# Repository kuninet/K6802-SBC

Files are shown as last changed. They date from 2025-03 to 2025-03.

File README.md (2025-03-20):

# MC6802 MPUを使ったシングルボードコンピューター

## REV1はシリアルクロック回路にバグがあります!!
## REV2で修正

## 概要
* MC6802 MPUを使ったシングルボードコンピューターです。
  * MC6850 ACIA経由でシリアルターミナル(TeraTermなど)とつながります。(SBC6800と互換)
  * 64kBのメモリー領域にRAMをわりあてるため128kB SRAMを使用しています。(半分の64kBは無駄にしています)
    * 半田ジャンパによりメモリー領域を調整可能です。(外部ボードのRAM用にディセーブル or ROM領域へ割り当て)
  * ROMは32kBタイプですが、ジャンパで2つの領域に分けて使用できます。
* SBC6800のソフトを使えることを目指しました。

## 回路図
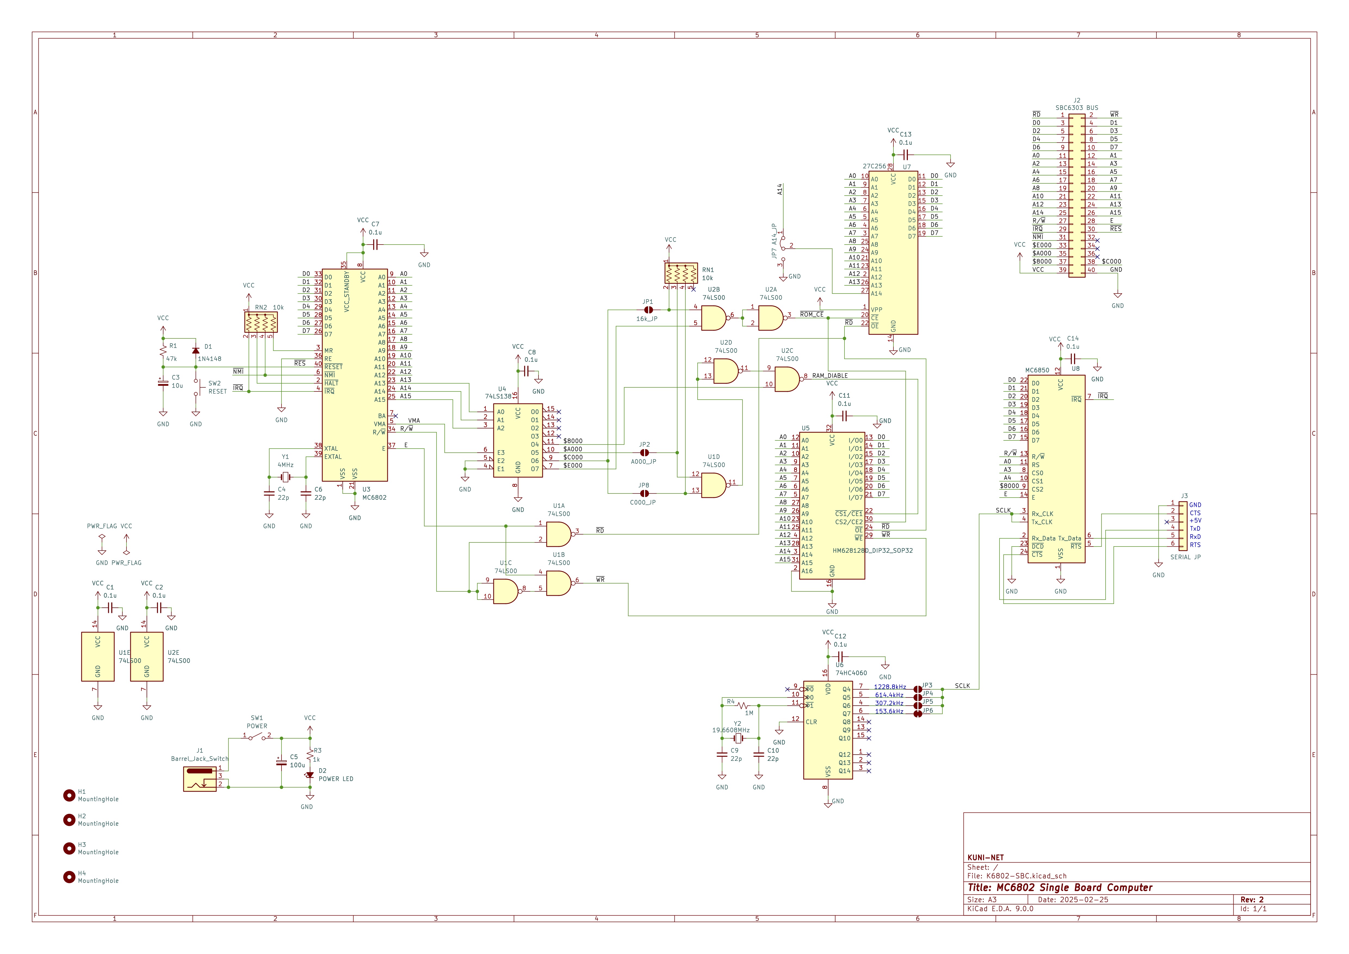
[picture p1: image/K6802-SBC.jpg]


## 部品表
[部品表](KiCad/K6802-SBC.csv)

## ブラウザで回路図などを確認
* Kicadcanvas
  * https://kicanvas.org/?github=https%3A%2F%2Fgithub.com%2Fkuninet%2FK6802-SBC%2Ftree%2Fmain%2FKiCad

## 参考
* 以下の回路を参考にさせていただきました。ありがとうございます。
  * [SBC6800 ルーズキット (電脳伝説さん)](https://vintagechips.wordpress.com/2017/12/05/sbc6800%E3%83%AB%E3%83%BC%E3%82%BA%E3%82%AD%E3%83%83%E3%83%88/)
  * [SBC-IO Rev02 (Tomi9さん)](https://sbc738827564.wordpress.com/2018/08/11/sbc-io-rev02/)
  * [SBC8080 SUBルーズキット (電脳伝説さん)](https://vintagechips.wordpress.com/2018/06/23/sbc8080-sub%E3%83%AB%E3%83%BC%E3%82%BA%E3%82%AD%E3%83%83%E3%83%88/)
  * [SBC6802 (ryu10さん)](https://github.com/ryu10/sbc6802)

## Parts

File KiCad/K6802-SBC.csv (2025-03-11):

Reference | Value | Datasheet | Footprint | Qty | DNP
C1,C2,C7,C8,C11,C12,C13,C14 | 0.1u | ~ | Capacitor_THT:C_Disc_D3.0mm_W2.0mm_P2.50mm | 8
C3 | 10u | ~ | Capacitor_THT:CP_Radial_D5.0mm_P2.50mm | 1
C4,C6,C9,C10 | 22p | ~ | Capacitor_THT:C_Disc_D3.0mm_W2.0mm_P2.50mm | 4
C5 | 100u | ~ | Capacitor_THT:CP_Radial_D5.0mm_P2.50mm | 1
D1 | 1N4148 | ~ | Diode_THT:D_A-405_P10.16mm_Horizontal | 1
D2 | POWER LED | ~ | LED_THT:LED_D3.0mm | 1
H1,H2,H3,H4 | MountingHole | ~ | MountingHole:MountingHole_3.2mm_M3 | 4
J1 | Barrel_Jack_Switch | ~ | Connector_BarrelJack:BarrelJack_Horizontal | 1
J2 | SBC6303 BUS | ~ | Connector_PinHeader_2.54mm:PinHeader_2x20_P2.54mm_Horizontal | 1
J3 | SERIAL JP | ~ | Connector_PinHeader_2.54mm:PinHeader_1x06_P2.54mm_Horizontal | 1
R1 | 47k | ~ | Resistor_THT:R_Axial_DIN0207_L6.3mm_D2.5mm_P10.16mm_Horizontal | 1
R3 | 1k | ~ | Resistor_THT:R_Axial_DIN0207_L6.3mm_D2.5mm_P10.16mm_Horizontal | 1
R4 | 1M | ~ | Resistor_THT:R_Axial_DIN0207_L6.3mm_D2.5mm_P10.16mm_Horizontal | 1
RN1,RN2 | 10k | http://www.vishay.com/docs/31509/csc.pdf | Resistor_THT:R_Array_SIP5 | 2
SW1 | POWER | ~ | Connector_PinHeader_2.54mm:PinHeader_1x03_P2.54mm_Vertical | 1
SW2 | RESET | ~ | Button_Switch_THT:SW_PUSH_6mm | 1
U1,U2 | 74LS00 | http://www.ti.com/lit/gpn/sn74ls00 | Package_DIP:DIP-14_W7.62mm_Socket | 2
U3 | MC6802 | https://www.jameco.com/Jameco/Products/ProdDS/43502.pdf | Package_DIP:DIP-40_W15.24mm_Socket | 1
U4 | 74LS138 | http://www.ti.com/lit/gpn/sn74LS138 | Package_DIP:DIP-16_W7.62mm_Socket | 1
U5 | HM628128D_DIP32_SOP32 | http://www.futurlec.com/Datasheet/Memory/628128.pdf | Package_DIP:DIP-32_W15.24mm_Socket | 1
U6 | 74HC4060 | https://www.st.com/resource/en/datasheet/m74hc4060.pdf | Package_DIP:DIP-16_W7.62mm_Socket | 1
U7 | 27C256 | http://ww1.microchip.com/downloads/en/DeviceDoc/doc0014.pdf | Package_DIP:DIP-28_W15.24mm_Socket | 1
U8 | MC6850 | http://pdf.datasheetcatalog.com/datasheet/motorola/MC6850.pdf | Package_DIP:DIP-24_W15.24mm_Socket | 1
Y1 | 4MHz | ~ | Crystal:Crystal_HC49-U_Vertical | 1
Y2 | 19.6608MHz | ~ | Crystal:Crystal_HC49-U_Vertical | 1

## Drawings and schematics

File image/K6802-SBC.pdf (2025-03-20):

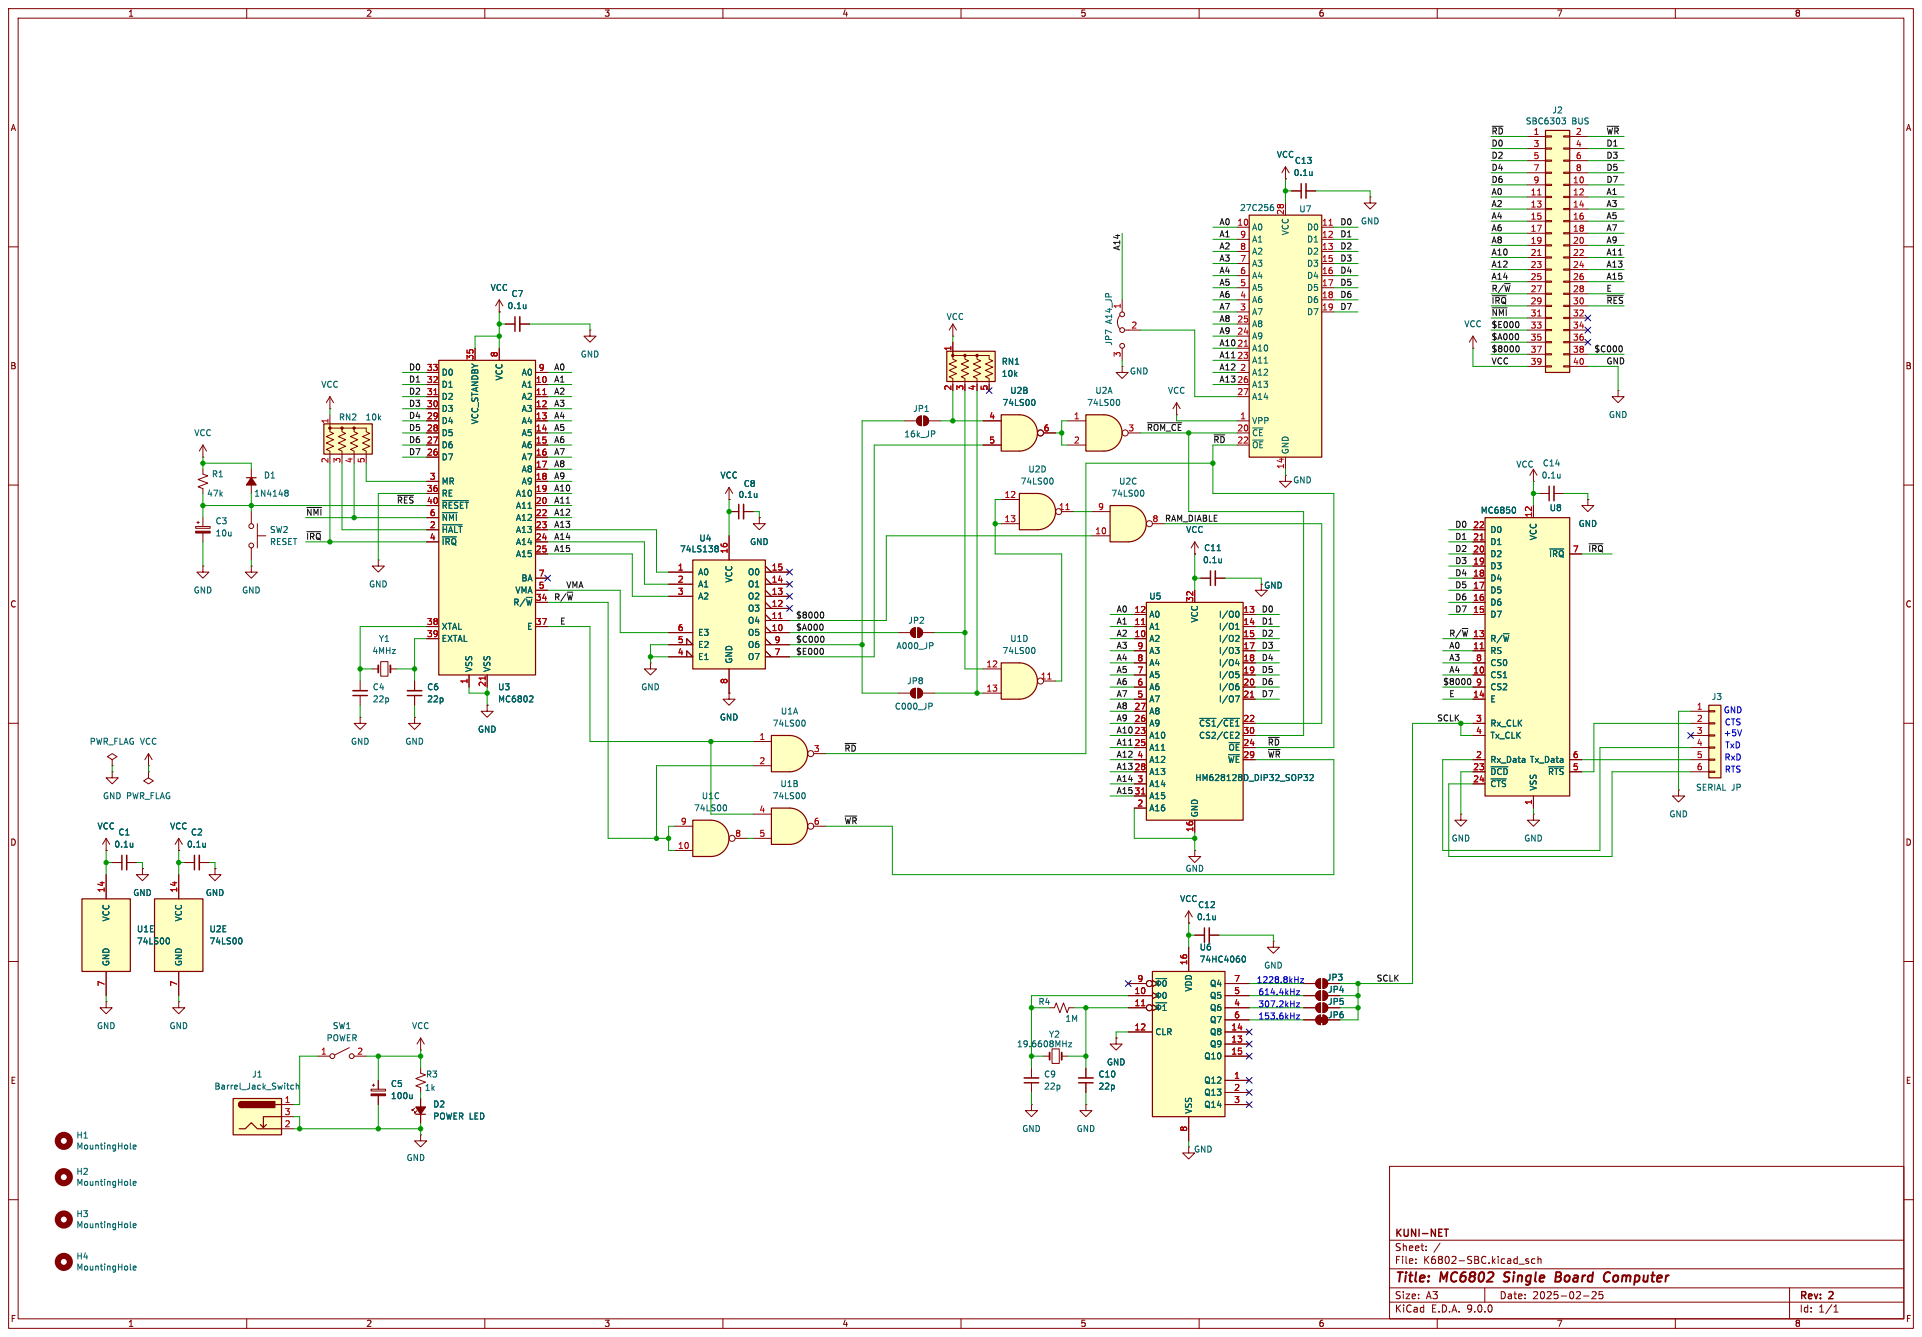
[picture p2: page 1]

H2 MountingHole H3 MountingHole H1 MountingHole H4 MountingHole

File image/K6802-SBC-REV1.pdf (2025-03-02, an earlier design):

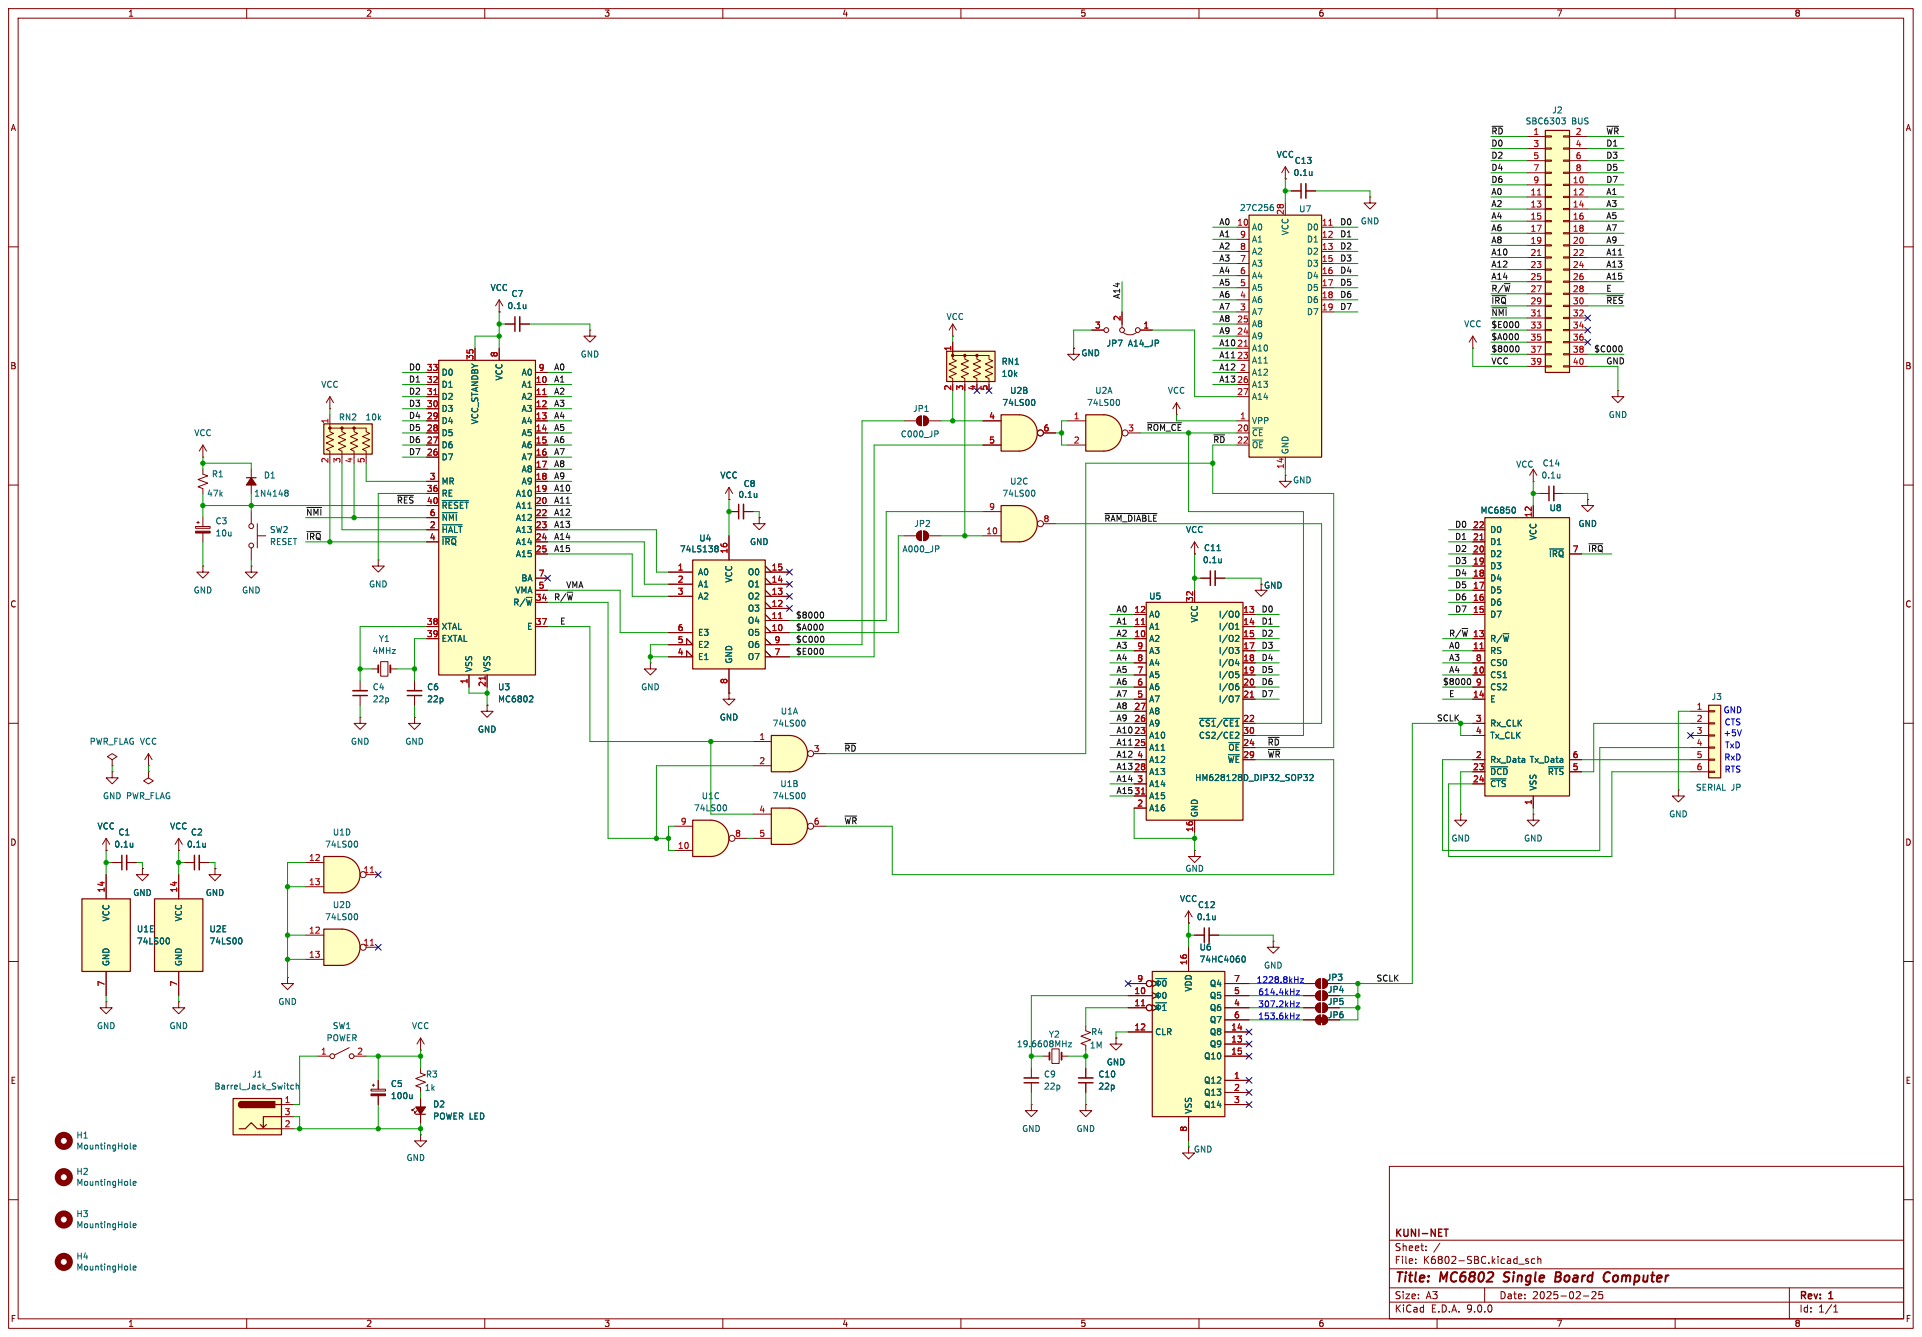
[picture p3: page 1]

1 ~{IRQ}7 Tx_Data 6 ~{RTS}5 MC6850 U8 SW2 RESET GND

Id: 1/1 Title: MC6802 Single Board Computer File: K6802-SBC.kicad_sch Sheet: / KUNI-NET GND

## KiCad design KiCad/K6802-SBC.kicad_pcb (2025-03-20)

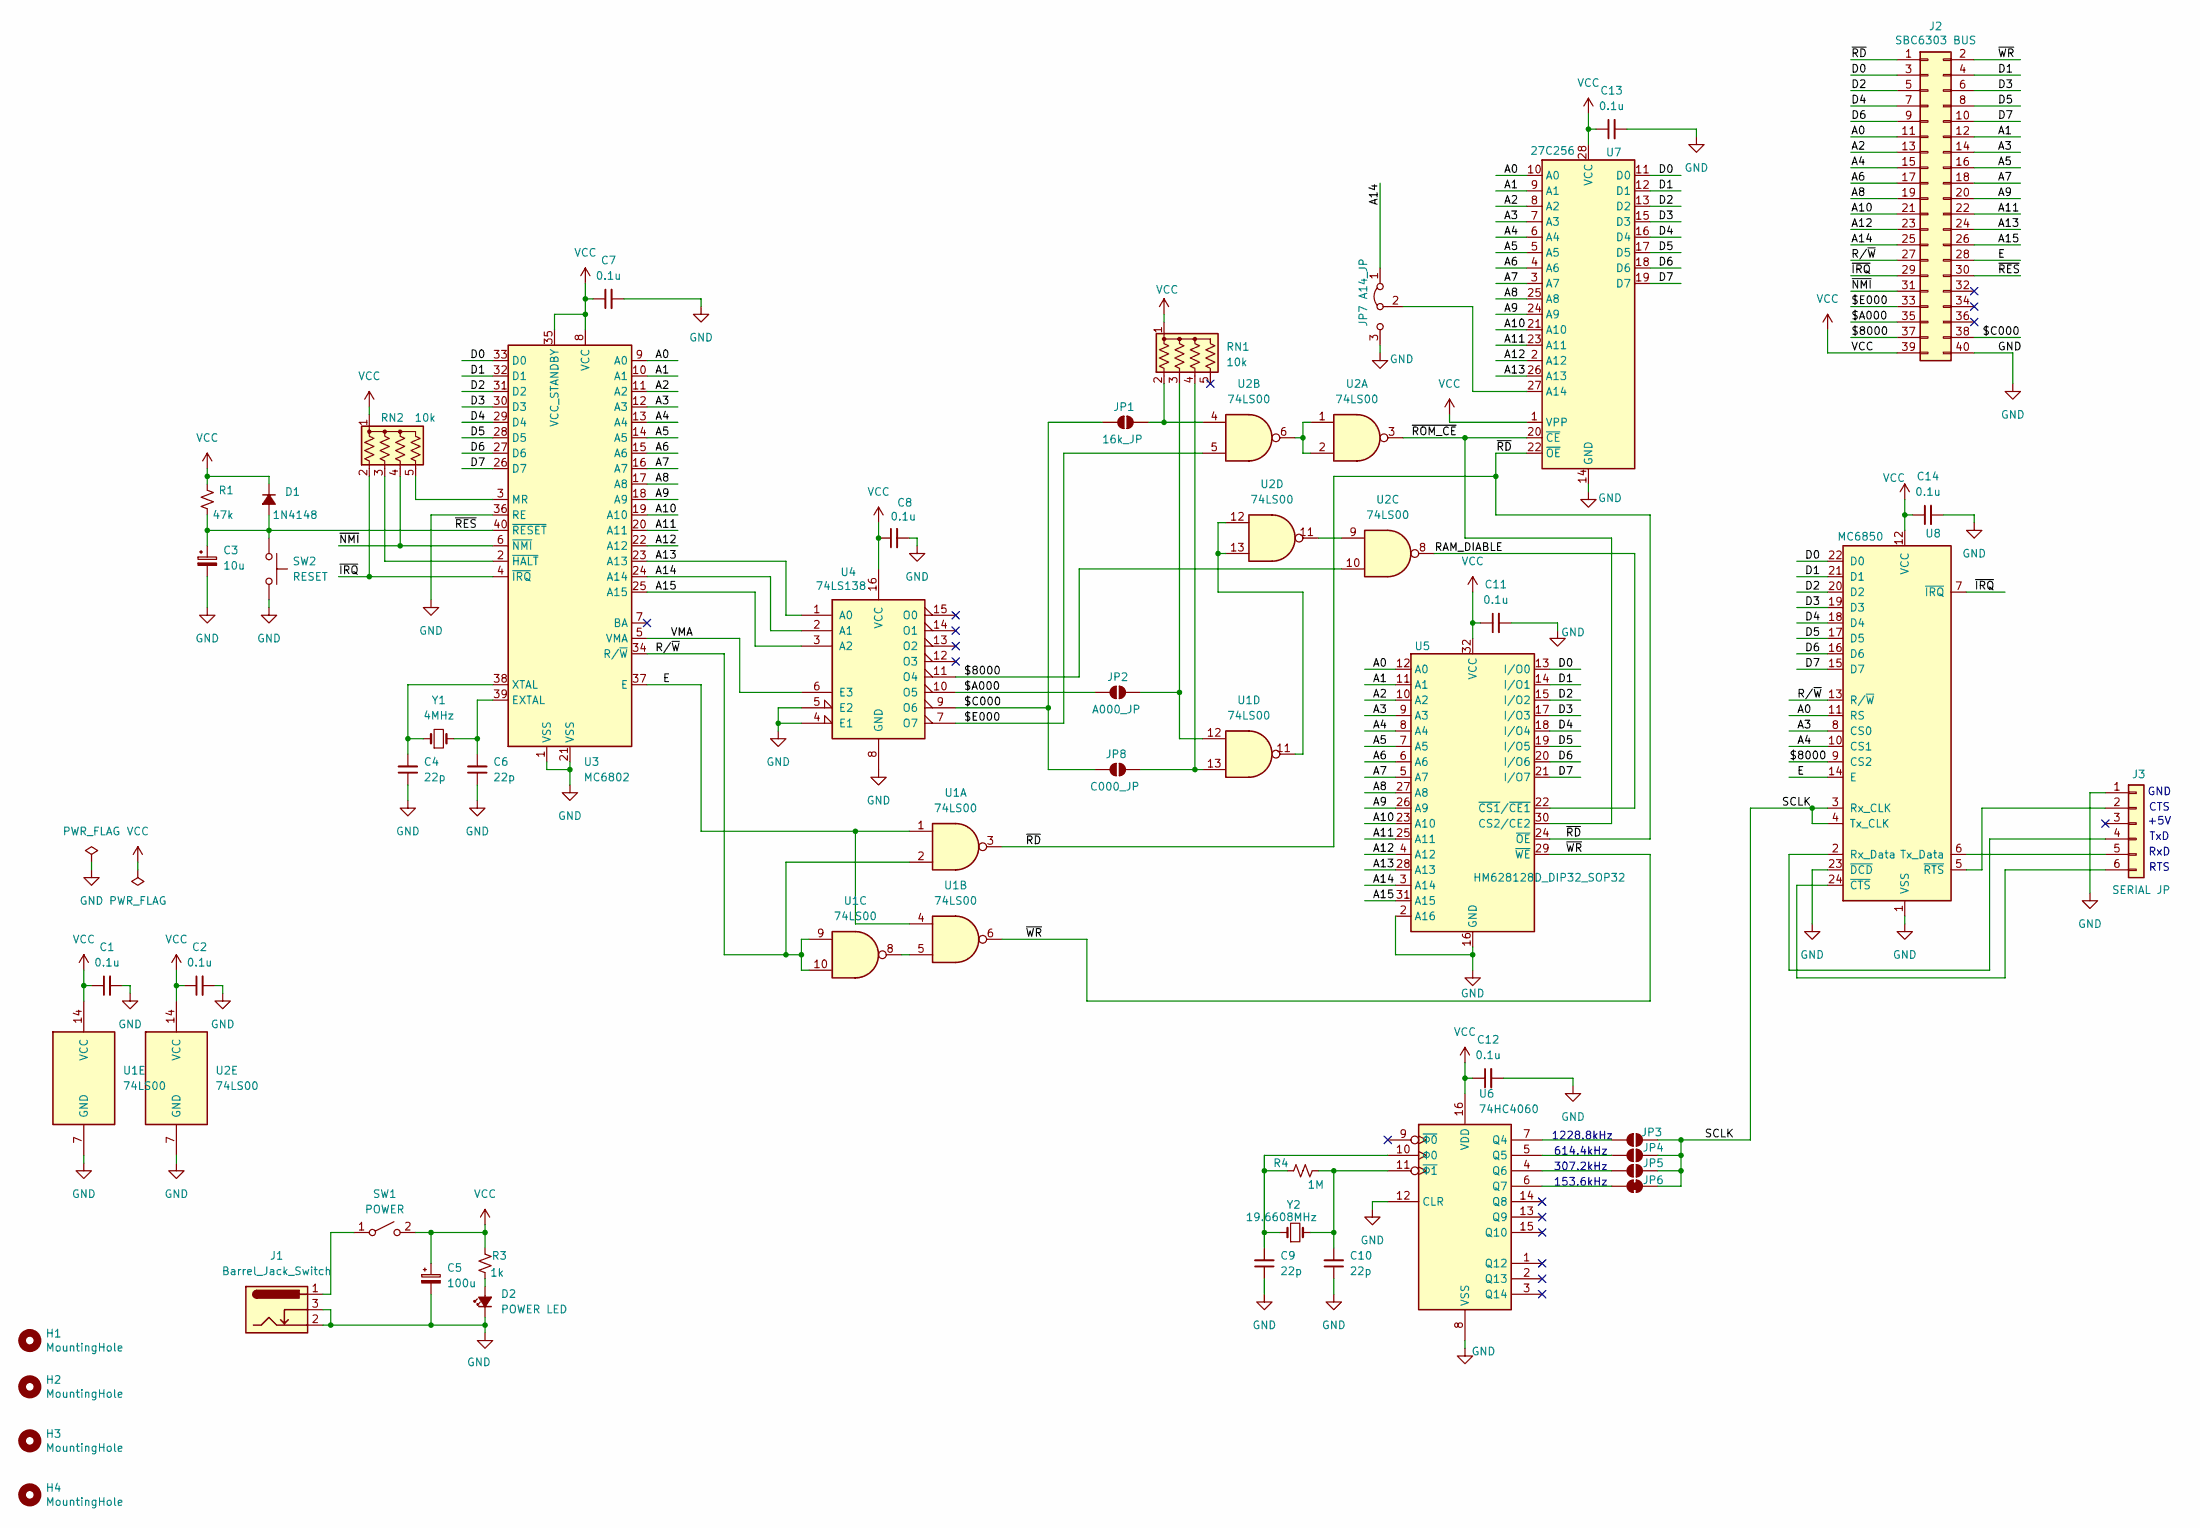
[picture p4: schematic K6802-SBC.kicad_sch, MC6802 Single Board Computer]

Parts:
C1, C2, C7, C8, C11, C12, C13, C14: 0.1u; C_Disc_D3.0mm_W2.0mm_P2.50mm
C3: 10u; CP_Radial_D5.0mm_P2.50mm
C4, C6, C9, C10: 22p; C_Disc_D3.0mm_W2.0mm_P2.50mm
C5: 100u; CP_Radial_D5.0mm_P2.50mm
D1: 1N4148; D_A-405_P10.16mm_Horizontal
D2: POWER LED; LED_D3.0mm
H1, H2, H3, H4: MountingHole; MountingHole_3.2mm_M3
J1: Barrel_Jack_Switch; BarrelJack_Horizontal
J2: SBC6303 BUS; PinHeader_2x20_P2.54mm_Horizontal
J3: SERIAL JP; PinHeader_1x06_P2.54mm_Horizontal
JP1: 16k_JP; SolderJumper-2_P1.3mm_Open_RoundedPad1.0x1.5mm
JP2: A000_JP; SolderJumper-2_P1.3mm_Open_RoundedPad1.0x1.5mm
JP3, JP4, JP5: SolderJumper-2_P1.3mm_Open_RoundedPad1.0x1.5mm
JP6: SolderJumper_2_Bridged; SolderJumper-2_P1.3mm_Bridged_RoundedPad1.0x1.5mm
JP7: A14_JP; PinHeader_1x03_P2.54mm_Vertical
JP8: C000_JP; SolderJumper-2_P1.3mm_Open_RoundedPad1.0x1.5mm
R1: 47k; R_Axial_DIN0207_L6.3mm_D2.5mm_P10.16mm_Horizontal
R3: 1k; R_Axial_DIN0207_L6.3mm_D2.5mm_P10.16mm_Horizontal
R4: 1M; R_Axial_DIN0207_L6.3mm_D2.5mm_P10.16mm_Horizontal
RN1, RN2: 10k; R_Array_SIP5
SW1: POWER; PinHeader_1x03_P2.54mm_Vertical
SW2: RESET; SW_PUSH_6mm
U1, U2: 74LS00; DIP-14_W7.62mm_Socket
U3: MC6802; DIP-40_W15.24mm_Socket
U4: 74LS138; DIP-16_W7.62mm_Socket
U5: HM628128D_DIP32_SOP32; DIP-32_W15.24mm_Socket
U6: 74HC4060; DIP-16_W7.62mm_Socket
U7: 27C256; DIP-28_W15.24mm_Socket
U8: MC6850; DIP-24_W15.24mm_Socket
Y1: 4MHz; Crystal_HC49-U_Vertical
Y2: 19.6608MHz; Crystal_HC49-U_Vertical

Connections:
/$8000: J2.37, U2.10, U4.11 (O4), U8.9 (CS2)
/$A000: J2.35, JP2.1 (A), U4.10 (O5)
/$C000: J2.38, JP1.1 (A), JP8.1 (A), U4.9 (O6)
/$E000: J2.33, U2.5, U4.7 (O7)
/A0: J2.11, U3.9 (A0), U5.12 (A0), U7.10 (A0), U8.11 (RS)
/A1: J2.12, U3.10 (A1), U5.11 (A1), U7.9 (A1)
/A2: J2.13, U3.11 (A2), U5.10 (A2), U7.8 (A2)
/A3: J2.14, U3.12 (A3), U5.9 (A3), U7.7 (A3), U8.8 (CS0)
/A4: J2.15, U3.13 (A4), U5.8 (A4), U7.6 (A4), U8.10 (CS1)
/A5: J2.16, U3.14 (A5), U5.7 (A5), U7.5 (A5)
/A6: J2.17, U3.15 (A6), U5.6 (A6), U7.4 (A6)
/A7: J2.18, U3.16 (A7), U5.5 (A7), U7.3 (A7)
/A8: J2.19, U3.17 (A8), U5.27 (A8), U7.25 (A8)
/A9: J2.20, U3.18 (A9), U5.26 (A9), U7.24 (A9)
/A10: J2.21, U3.19 (A10), U5.23 (A10), U7.21 (A10)
/A11: J2.22, U3.20 (A11), U5.25 (A11), U7.23 (A11)
/A12: J2.23, U3.22 (A12), U5.4 (A12), U7.2 (A12)
/A13: J2.24, U3.23 (A13), U4.1 (A0), U5.28 (A13), U7.26 (A13)
/A14: J2.25, JP7.1 (A), U3.24 (A14), U4.2 (A1), U5.3 (A14)
/A15: J2.26, U3.25 (A15), U4.3 (A2), U5.31 (A15)
/D0: J2.3, U3.33 (D0), U5.13 (I/O0), U7.11 (D0), U8.22 (D0)
/D1: J2.4, U3.32 (D1), U5.14 (I/O1), U7.12 (D1), U8.21 (D1)
/D2: J2.5, U3.31 (D2), U5.15 (I/O2), U7.13 (D2), U8.20 (D2)
/D3: J2.6, U3.30 (D3), U5.17 (I/O3), U7.15 (D3), U8.19 (D3)
/D4: J2.7, U3.29 (D4), U5.18 (I/O4), U7.16 (D4), U8.18 (D4)
/D5: J2.8, U3.28 (D5), U5.19 (I/O5), U7.17 (D5), U8.17 (D5)
/D6: J2.9, U3.27 (D6), U5.20 (I/O6), U7.18 (D6), U8.16 (D6)
/D7: J2.10, U3.26 (D7), U5.21 (I/O7), U7.19 (D7), U8.15 (D7)
/E: J2.28, U1.1, U1.4, U3.37 (E), U8.14 (E)
/RAM_DIABLE: U2.8, U5.22 (~CS1/~CE1)
/R/~W: J2.27, U1.2, U1.9, U1.10, U3.34 (R/~W), U8.13 (R/~W)
/SCLK: JP3.2 (B), JP4.2 (B), JP5.2 (B), JP6.2 (B), U8.3 (Rx_CLK), U8.4 (Tx_CLK)
/VMA: U3.5 (VMA), U4.6 (E3)
/~IRQ: J2.29, RN2.2 (R1), U3.4 (~IRQ), U8.7 (~IRQ)
/~NMI: J2.31, RN2.4 (R3), U3.6 (~NMI)
/~RD: J2.1, U1.3, U5.24 (~OE), U7.22 (~OE)
/~RES: C3.1, D1.2 (A), J2.30, R1.2, SW2.1, U3.40 (~RESET)
/~ROM_CE: U2.3, U5.30 (CS2/CE2), U7.20 (~CE)
/~WR: J2.2, U1.6, U5.29 (~WE)
GND: C1.2, C2.2, C3.2, C4.1, C5.2, C6.1, C7.2, C8.2, C9.1, C10.1, C11.2, C12.2, C13.2, C14.2, D2.1 (K), J1.2, J1.3, J2.40, J3.1, JP7.3 (B), SW2.2, U1.7 (GND), U2.7 (GND), U3.1 (VSS), U3.21 (VSS), U3.36 (RE), U4.4 (E1), U4.5 (E2), U4.8 (GND), U5.2 (A16), U5.16 (GND), U6.8 (VSS), U6.12 (CLR), U7.14 (GND), U8.1 (VSS), U8.23 (~DCD)
unnamed: D2.2 (A), R3.2
unnamed: J3.2, U8.5 (~RTS)
unnamed: J3.4, U8.2 (Rx_Data)
unnamed: J3.5, U8.6 (Tx_Data)
unnamed: J3.6, U8.24 (~CTS)
unnamed: JP1.2 (B), RN1.2 (R1), U2.4
unnamed: JP2.2 (B), RN1.3 (R2), U1.12
unnamed: JP3.1 (A), U6.7 (Q4)
unnamed: JP4.1 (A), U6.5 (Q5)
unnamed: JP5.1 (A), U6.4 (Q6)
unnamed: JP6.1 (A), U6.6 (Q7)
unnamed: JP7.2 (C), U7.27 (A14)
unnamed: JP8.2 (B), RN1.4 (R3), U1.13
unnamed: RN2.3 (R2), U3.2 (~HALT)
unnamed: RN2.5 (R4), U3.3 (MR)
unnamed: J1.1, SW1.1 (A)
unnamed: U1.5, U1.8
unnamed: U1.11, U2.12, U2.13
unnamed: U2.1, U2.2, U2.6
unnamed: U2.9, U2.11
unnamed: C6.2, U3.39 (EXTAL), Y1.2
unnamed: C4.2, U3.38 (XTAL), Y1.1
unnamed: C10.2, R4.2, U6.11 (~Φ1), Y2.2
unnamed: C9.2, R4.1, U6.10 (Φ0), Y2.1
VCC: C1.1, C2.1, C5.1, C7.1, C8.1, C11.1, C12.1, C13.1, C14.1, D1.1 (K), J2.39, R1.1, R3.1, RN1.1 (common), RN2.1 (common), SW1.2 (B), U1.14 (VCC), U2.14 (VCC), U3.8 (VCC), U3.35 (VCC_STANDBY), U4.16 (VCC), U5.32 (VCC), U6.16 (VDD), U7.1 (VPP), U7.28 (VCC), U8.12 (VCC)

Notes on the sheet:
GND
153.6kHz
CTS
+5V
RxD
307.2kHz
614.4kHz
1228.8kHz
RTS
TxD

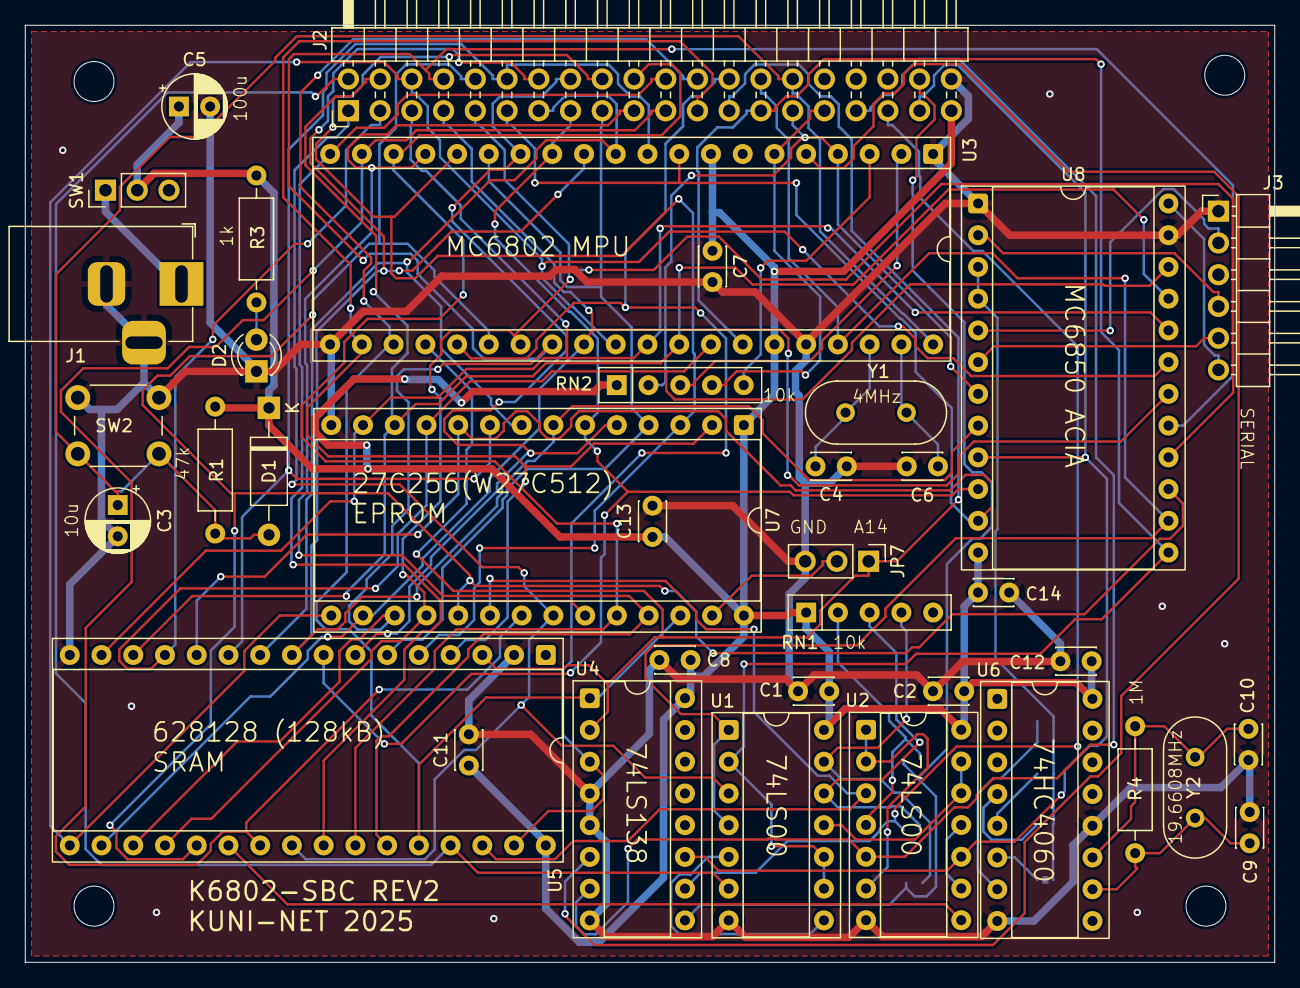
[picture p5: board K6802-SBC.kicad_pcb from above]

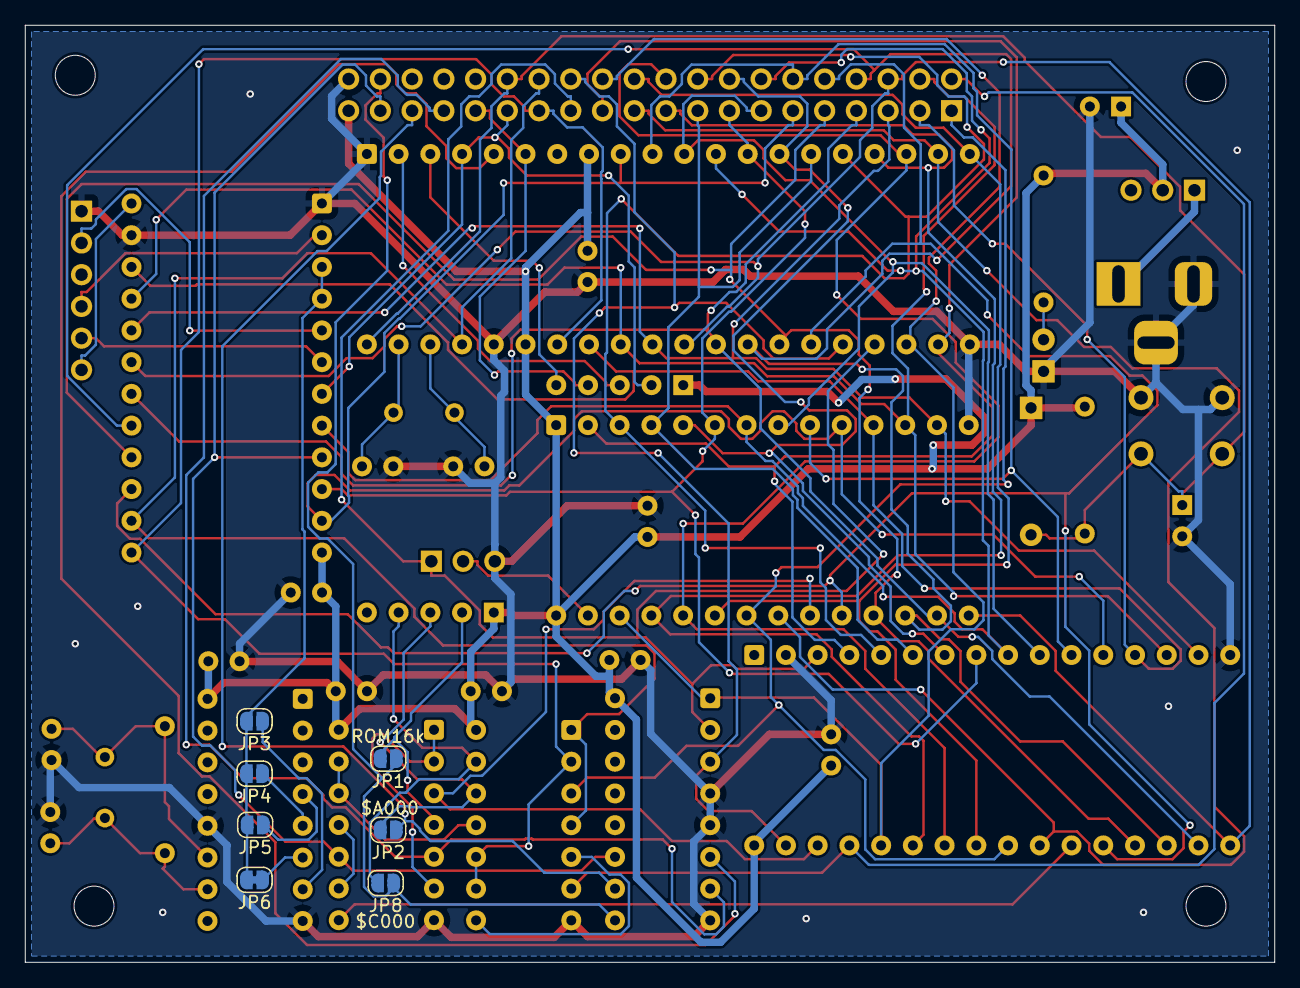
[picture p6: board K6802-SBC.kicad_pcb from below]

Board: 2 copper layers, 100.0 x 75.0 mm, 48 parts (7 on the bottom side), 65 nets.

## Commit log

2025-03-01 init commit
    [K6802-SBC.kicad_pcb, K6802-SBC.kicad_sch]
2025-03-02 プリントパターン作成、ガーバーデータ出力
    [K6802-SBC-B_Cu.gbl, K6802-SBC-B_Mask.gbs, K6802-SBC-B_Silkscreen.gbo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]
2025-03-11 シリアルクロック間違い修正(回路図だけ)
    [K6802-SBC.csv, K6802-SBC.kicad_sch]
2025-03-18 メモリーマップ図追加
2025-03-20 ROM16k-8k図作成
2025-03-20 .gitignore変更
2025-03-20 $C000無効かジャンパ追加 REV2ガーバー出力
    [K6802-SBC-B_Cu.gbl, K6802-SBC-B_Mask.gbs, K6802-SBC-B_Silkscreen.gbo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]
